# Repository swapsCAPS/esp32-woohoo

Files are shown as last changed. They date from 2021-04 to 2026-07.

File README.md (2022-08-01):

# ESP32 + BME280 IoT Project

## BOM
- DFRobot Firebeetle ESP32-E
- 3.7V LiPo battery
- BME280
- Rectangular rocker switch

## ESP32 WiFi woes
My router does not play nice with ESP32's it seems. Using my phone's hotspot, connecting to the internet and getting a time from NTP works fine.
I **am** getting an IP address, so I know the credentials are correct. But it seems I can't reach the internet, and get disconnected fairly quickly after connecting.  
I fiddled with the security settings and changed from WPA2 + WPA3 to WPA + WPA2 and all of a sudden the ESP32 connected fine. Yay! Wanting to be thorough, I tried using WPA2 + WPA3 mode again to see if I could reproduce my issue. But no! For some weird reason it just keeps connecting now. Needs some more testing. I'll be testing a deep sleep script that sleeps for 10 minutes, then when it wakes up, gets the time and logs if it succeeded or failed to `Serial`.
According to some sources you need to disconnect wifi before deep sleep. I have not been able to reproduce consistent failures by _not_ disconnecting though, so I'll test without that first.
Seems that I successfully got ntp time every 10 minutes. Trying with WPA2 + WPA3 for a couple of cycles. Something weird is going on with my router. I should try turning it off and on again and/or doing a hard reset.  
Could it be there is some weird stateful thing going on?  
**Update:** After tweaking WPA settings back and forth, something in the modem appears to have been nudged. I'm getting consistently connected now, and can not reproduce my issue... I have not touched anything else, I should have probably just reset my modem, before diving into the software side of things.  
**Update 2:** WPA setting does not appear to persist properly, and it appears I have been using WPA + WPA2 this whole time... Come h4ck me!

## Battery life
Experimenting with two devices with their jumper wire cut. Leaving one as is. Will turn them on at the same time. and see how long each will last.  
**Update** I've left two devices side by side, in an attempt to minimize the WiFi interference component of the measurement. Weirdly, after 24 hours the one with its jumper cut is reporting a lower battery level than the one without the jumper cut. It's probably still just too early to say, on top of that, there are a lot of other variables that could influence the reading.

## Weird readings
Sometimes I'm getting way too high or way too low pressure and humidity readings. Experimenting with initializing the BME on start up, instead of right before taking measurement.  
**Update** This has helped, although I still sometimes get a very low pressure reading. It seems like the BME280 needs some time to initialize.

## Devices
Battery powered ESP32 + BME280 modules.  
They take a measurement, send it to an mqtt broker and go to sleep for `TIME_TO_SLEEP`, defined in `./config.h`.  
Arduino code can be found in `./esp32-woohoo.ino`

## Server
Simple rust mqtt scraper to expose prometheus metrics.  
Code can be found in `./mqtt-to-prom`  
Grafana dashboard available in `./mqtt-to-prom/meta/grafana-dashboard.json`

## MQTT
If using mosquitto and running in a safe environment set
```
# /etc/mosquitto/mosquitto.conf
listener 1883 0.0.0.0 # Allow external connections
allow_anonymous true  # We have not set up auth
```

## Build

### esp32-woohoo.ino
- Add the FireBeetle ESP32-E board in Arduino IDE Boards Manager
  - In Arduino IDE -> File -> Preferences -> Additional Boards Manager URLs, add: `http://download.dfrobot.top/FireBeetle/package_DFRobot_index.json`
    - This is for the DFRobot ESP32-E version!
    - Their server is slow af, grab coffee
  - Select the board in Arduino IDE -> Tools -> Board -> DFRobot ESP32 Arduino -> DFRobot FireBeetle ESP32-E
- Ensure the following libs are installed
  - WiFi by Arduino `1.2.7`
  - FastLED by Daniel Garcia `3.5.0`
  - Adafruit Unified Sensor `1.15`
  - Adafruit BME280 Library `2.2.2`
  - https://github.com/marvinroger/async-mqtt-client
- Add a `secret.h` file in the root of the project with WiFi credentials
  ```c
  // ./secret.h
  #define WIFI_SSID "SSID"
  #define WIFI_PASSWORD "hunter1" // lol
  ```

### mqtt-to-prom
Make sure [cross](https://github.com/rust-embedded/cross) is installed
```
cargo install cross
```
If running on raspberry pi 4 with aarch64 run:
```bash
make build-pi
```

## TODO
- [x] Add timer to go back to sleep if connection not made
- [x] Round values to eliminate "noise"
- [x] [bugfix] parsing float goes wrong sometimes, write some tests
  - [x] test this
  - [x] output payload on parse error
  - [ ] check if happens again
- [x] Grafana dashboard
- [x] NTP server call
- [x] Send out time stamps
- [ ] Blink on connection failures?
  - [ ] Needs some experimentation, might substantially reduce batter life
- [ ] Improve battery life
  - [x] Read out SoC (on A0?)
    - [x] Using voltage divider (10KΩ + 20KΩ)
  - [x] Reduce/disable LED on time
  - [x] Reduce amount of measurements taken, i.e. increase sleep time
  - [ ] Go back to deep sleep after several connection failures
  - [ ] Get better idea of battery level percentage (0-4096 but cuts out at 2000 or smth)
  - [ ] If possible light up when battery too low
- [x] Add last will on connect()
    - [ ] Decided to skip this for now. Will do server side most likely.
- [ ] Auto config server. Loop over serial ports, check for devices and flash config to them.
  - [ ] Auto config server
  - [ ] Use EEPROM to store wifi credentials, broker location, etc.

## Media
3D printed case, check `./stl` for files.
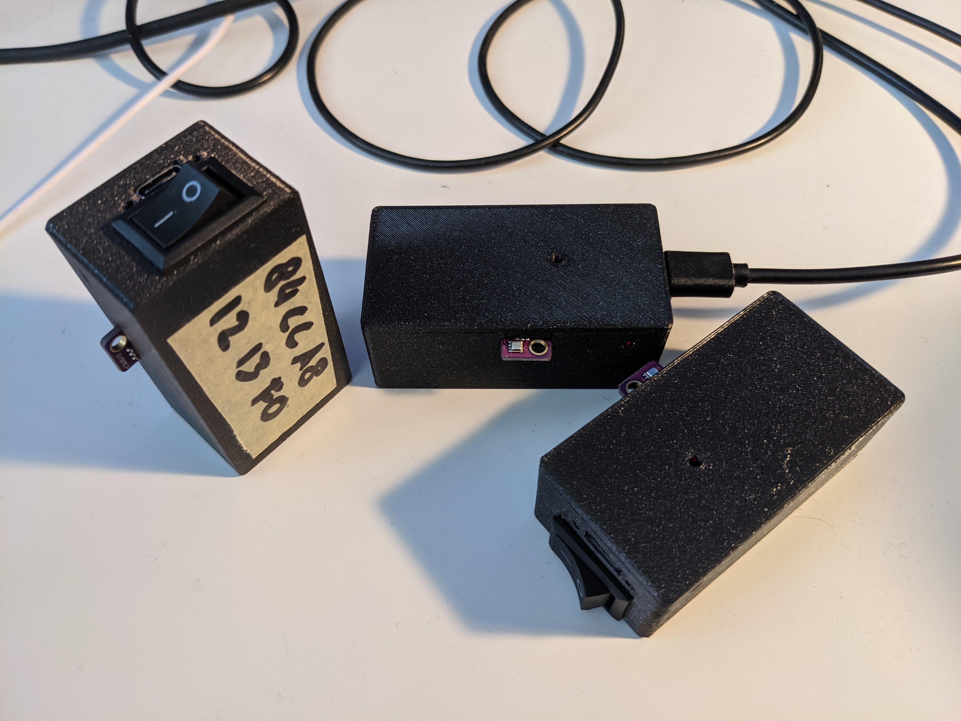
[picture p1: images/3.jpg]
Aint they cute?!


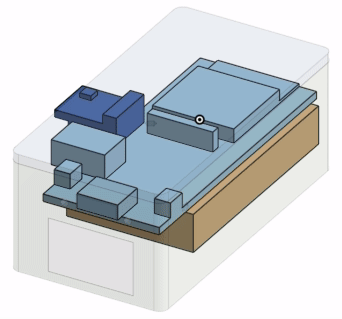
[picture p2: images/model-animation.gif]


Deep sleep, wake, connect wifi, connect mqtt, take measurement, send measurement, deep sleep...  
Oooh look at the pretty lights!

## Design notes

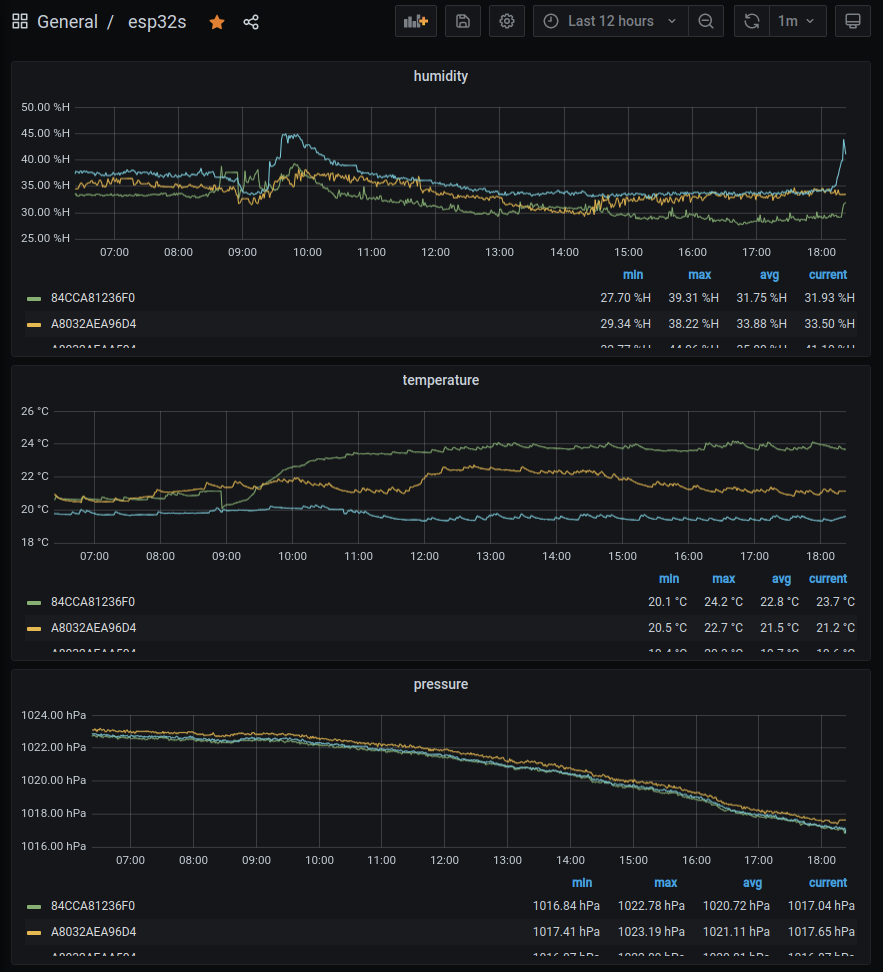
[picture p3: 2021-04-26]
images/grafana-dashboard.png

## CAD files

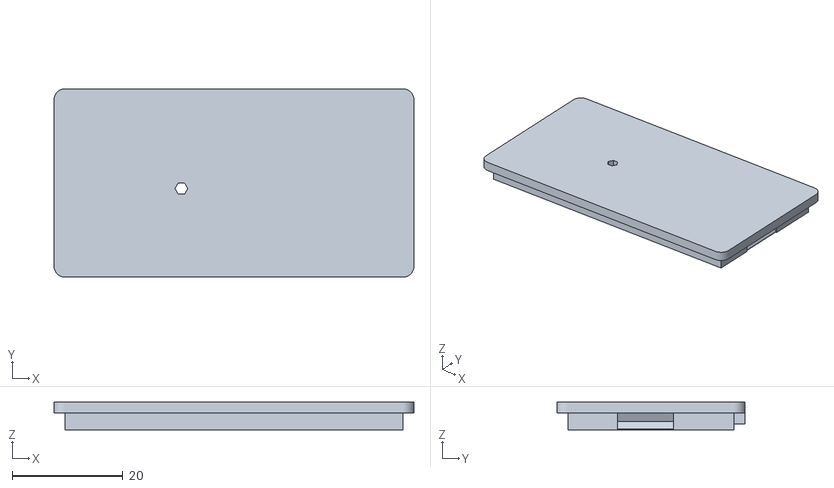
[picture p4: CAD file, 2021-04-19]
stl/hum-sensor-v2 - lid.stl
65.0 x 34.0 x 5.00

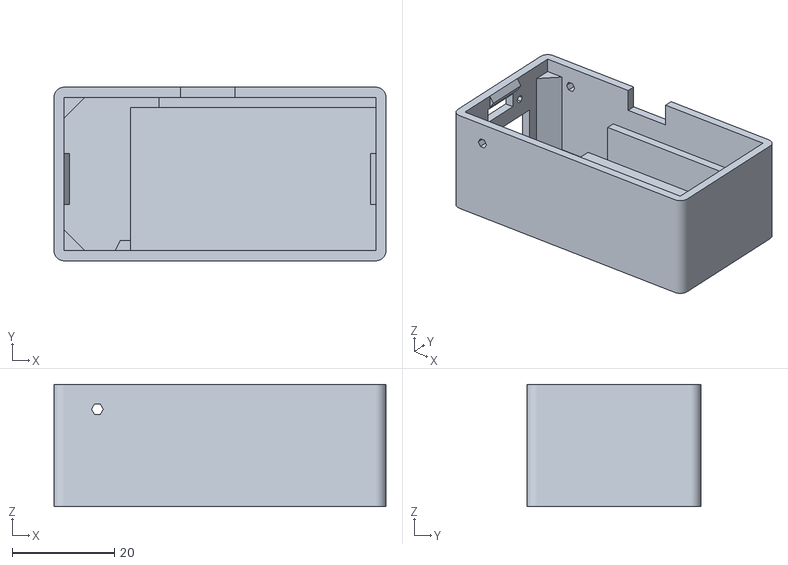
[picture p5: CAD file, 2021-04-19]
stl/hum-sensor-v2 - box.stl
65.0 x 34.0 x 23.9

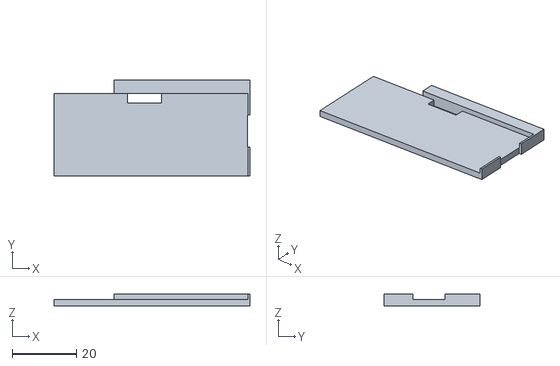
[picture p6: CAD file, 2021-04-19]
stl/hum-sensor-v2 - shim.stl
60.8 x 29.9 x 3.60

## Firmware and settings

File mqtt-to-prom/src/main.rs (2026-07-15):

#[macro_use]
extern crate prometheus;
#[macro_use]
extern crate lazy_static;
#[macro_use]
extern crate log;
extern crate pretty_env_logger;

use prometheus::{Encoder, GaugeVec, TextEncoder};
use rumqttc::{Client, Event, Incoming, MqttOptions, QoS};
use std::env;
use std::io::prelude::*;
use std::net::{TcpListener, TcpStream};
use std::str;
use std::thread;

lazy_static! {
    static ref TEMPERATURE_GAUGE: GaugeVec =
        register_gauge_vec!("esp32_temperature", "Temperature", &["mac"]).unwrap();
    static ref HUMIDITY_GAUGE: GaugeVec =
        register_gauge_vec!("esp32_humidity", "Humidity", &["mac"]).unwrap();
    static ref PRESSURE_GAUGE: GaugeVec =
        register_gauge_vec!("esp32_pressure", "Pressure", &["mac"]).unwrap();
    static ref BATTERY_LEVEL: GaugeVec =
        register_gauge_vec!("esp32_bat_lvl", "Battery level", &["mac"]).unwrap();
    static ref EPOCH: GaugeVec = register_gauge_vec!("esp32_epoch", "Epoch", &["mac"]).unwrap();
    static ref MEASUREMENT_SUCCESS: GaugeVec = register_gauge_vec!(
        "esp32_measurement_success",
        "Times taking a measurement succeeded",
        &["mac"]
    )
    .unwrap();
    static ref MEASUREMENT_FAILURE: GaugeVec = register_gauge_vec!(
        "esp32_measurement_failure",
        "Times measurement failed",
        &["mac"]
    )
    .unwrap();
}

fn main() {
    pretty_env_logger::init();
    info!("Starting mqtt thread...");

    let mqtt_host = env::var("MQTT_HOST").unwrap_or(String::from("localhost"));
    let bind_address = env::var("TCP_BIND_ADDR").unwrap_or(String::from("localhost:19090"));

    info!("mqtt_host {}", mqtt_host);
    info!("bind_address {}", bind_address);

    // --- MQTT Thread ---
    thread::spawn(move || {
        let mut mqttoptions = MqttOptions::new("esp32-server", mqtt_host, 1883);
        mqttoptions.set_keep_alive(5);

        let (mut client, mut connection) = Client::new(mqttoptions, 10);

        // Wrap subscription in case of early errors
        if let Err(e) = client.subscribe("sensors/thp/+", QoS::AtMostOnce) {
            error!("Failed to subscribe: {:?}", e);
        }

        // Process MQTT notifications
        for (i, notification) in connection.iter().enumerate() {
            // Every 1000 events, log a heartbeat to see if this loop is flooding
            if i % 1000 == 0 {
                debug!("MQTT Loop Heartbeat: processed {} events", i);
            }

            match notification {
                Ok(Event::Incoming(Incoming::Publish(p))) => {
                    let mac = match p.topic.split("/").last() {
                        Some(m) => m,
                        None => {
                            warn!("Failed to extract mac from topic: {}", p.topic);
                            continue;
                        }
                    };

                    let payload = match str::from_utf8(&p.payload) {
                        Ok(v) => v,
                        Err(_) => {
                            warn!("Invalid UTF-8 payload");
                            continue;
                        }
                    };

                    let split: Vec<&str> = payload.split(",").collect();

                    if let [temp, h, p, b, epoch, success, failure] = &split[..] {
                        if let Ok(result) = temp.trim().parse::<f64>() {
                            TEMPERATURE_GAUGE
                                .with_label_values(&[mac])
                                .set((result * 4.0).round() / 4.0);
                        }
                        if let Ok(result) = h.trim().parse::<f64>() {
                            HUMIDITY_GAUGE
                                .with_label_values(&[mac])
                                .set((result * 4.0).round() / 4.0);
                        }
                        if let Ok(result) = p.trim().parse::<f64>() {
                            PRESSURE_GAUGE
                                .with_label_values(&[mac])
                                .set((result * 4.0).round() / 4.0);
                        }
                        if let Ok(result) = b.trim().parse::<f64>() {
                            BATTERY_LEVEL.with_label_values(&[mac]).set(result);
                        }
                        if let Ok(result) = epoch.trim().parse::<f64>() {
                            EPOCH.with_label_values(&[mac]).set(result);
                        }
                        if let Ok(result) = success.trim().parse::<f64>() {
                            MEASUREMENT_SUCCESS.with_label_values(&[mac]).set(result);
                        }
                        if let Ok(result) = failure.trim().parse::<f64>() {
                            MEASUREMENT_FAILURE.with_label_values(&[mac]).set(result);
                        }
                    } else {
                        warn!("Could not split payload from {}", payload);
                    }
                }
                Ok(_other) => {
                    // Ignore non-publish events (pings, acks, etc) to prevent log flooding
                }
                Err(e) => {
                    error!("MQTT connection error: {:?}", e);
                    // Crucial: Sleep on error to prevent spinning during broker outage
                    thread::sleep(std::time::Duration::from_secs(2));
                }
            }
        }
    });

    // --- TCP Server (Prometheus Scrape Endpoint) ---
    let listener = TcpListener::bind(bind_address).unwrap();
    info!("Starting server...");

    for stream in listener.incoming() {
        let mut stream = match stream {
            Ok(s) => s,
            Err(e) => {
                error!("TCP incoming stream connection error: {:?}", e);
                thread::sleep(std::time::Duration::from_millis(50)); // Prevent hot loop if OS runs out of FDs
                continue;
            }
        };

        debug!("Request received");
        let mut req = [0; 1024];

        // Read from stream defensively
        match stream.read(&mut req) {
            Ok(0) => {
                // Client connected and immediately closed (EOF)
                debug!("Client closed connection immediately (0 bytes read)");
                continue;
            }
            Ok(n) => {
                debug!("Read {} bytes", n);
            }
            Err(e) => {
                warn!("Failed to read from TCP stream: {:?}", e);
                continue;
            }
        }

        let mut buffer = vec![];
        let encoder = TextEncoder::new();
        let metric_families = prometheus::gather();
        encoder.encode(&metric_families, &mut buffer).unwrap();

        let res = format!(
            "HTTP/1.1 200 OK\r\nContent-Length: {}\r\nConnection: close\r\n\r\n{}",
            buffer.len(),
            str::from_utf8(&buffer).unwrap()
        );

        if let Err(e) = stream.write_all(res.as_bytes()) {
            warn!("Failed to write TCP response: {:?}", e);
        }
        let _ = stream.flush();
    }
}

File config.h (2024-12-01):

#define SEALEVELPRESSURE_HPA 1013.00

// Time to sleep after taking a measurement
#define TIME_TO_SLEEP 10 * 60

// Go back to sleep if no measurement was taken withing this time
#define DEADMAN_SWITCH_MS 30 * 1000

#define MQTT_HOST IPAddress(192, 168, 178, 147)
#define MQTT_PORT 1883

// Hooked up using voltage divider
// In this case using 10K and 22K resistors I had laying around
int batteryLevelPin = A0;

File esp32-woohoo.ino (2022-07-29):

#include <FastLED.h>
#include <WiFi.h>
#include <Wire.h>
#include <Adafruit_Sensor.h>
#include <Adafruit_BME280.h>
#include <AsyncMqttClient.h>
#include "time.h"

#include "secret.h"
#include "config.h"

extern "C" {
#include "freertos/FreeRTOS.h"
#include "freertos/timers.h"
}

#define NUM_LEDS 1
#define DATA_PIN 5
#define CLOCK_PIN 13
#define uS_TO_S_FACTOR 1000000
#define I2C_SDA 21
#define I2C_SCL 22

RTC_DATA_ATTR int successCounter = 0;
RTC_DATA_ATTR int failureCounter = 0;

bool succeeded = false;

const char* ntpServer = "pool.ntp.org";
unsigned long epochTime;

TimerHandle_t deadmanSwitch;

CRGB leds[NUM_LEDS];
Adafruit_BME280 bme;

// Recommended delay time between reading from Bosch Sensortec
unsigned long delayTime;

byte macAddress[6];

char ssid[32];
char pass[20];

char macAddressStrArr[18];
char topicBuffie[32];
char pubBuffie[128];
char valBuffie[64];

AsyncMqttClient mqttClient;

void _configTime() {
    Serial.println("-- _configTime()");
    configTime(0, 0, ntpServer);
}

// Function that gets current epoch time
unsigned long getTime() {
  Serial.println("-- getTime()");
  time_t now;
  struct tm timeinfo;
  Serial.println("-- getTime() getting local time");
  if (!getLocalTime(&timeinfo)) {
    Serial.println("-- getTime() could not get time : (");
    return(0);
  }
  time(&now);
  Serial.println("-- getTime() done");

  return now;
}

void array_to_string(byte array[], unsigned int len, char buffer[]) {
  for (unsigned int i = 0; i < len; i++) {
    byte nib1 = (array[i] >> 4) & 0x0F;
    byte nib2 = (array[i] >> 0) & 0x0F;

    uint8_t offset = i;

    buffer[i*2+0] = nib1  < 0xA ? '0' + nib1  : 'A' + nib1  - 0xA;
    buffer[i*2+1] = nib2  < 0xA ? '0' + nib2  : 'A' + nib2  - 0xA;

    if (i == len - 1) { break; }

    buffer[i*2+2] = ':';
  }
  buffer[len*2] = '\0';
}

void setLED(uint32_t val) {
  leds[0] = val;
  FastLED.show();
}

void setMacAddressStr() {
  array_to_string(macAddress, 6, macAddressStrArr);
}

void setTopicBuffie() {
  strcat(topicBuffie, "sensors/thp/");
  strcat(topicBuffie, macAddressStrArr);
}

void blinkDelay(uint16_t ival, uint8_t times, uint32_t color) {
  for (uint8_t i = 0; i < times; i++) {
    setLED(color);
    delay(ival / 2);
    setLED(0x000000);
    delay(ival / 2);
  }
}

void onDeadmanSwitch() {
  Serial.println("-- onDeadmanSwitch() triggered!");
  goToSleep();
}

void connectToWifi() {
  Serial.println("-- connectToWifi");
  WiFi.begin(WIFI_SSID, WIFI_PASSWORD);
}

void connectToMqtt() {
  Serial.println("-- connectToMqtt");
  mqttClient.connect();
}

void onWiFiEvent(WiFiEvent_t event) {
  Serial.printf("-- onWiFiEvent() event: %d\n", event);
  switch(event) {
    case SYSTEM_EVENT_STA_GOT_IP:
      Serial.print("-- onWiFiEvent() connected to ");
      Serial.print(ssid);
      Serial.print(" with ");
      Serial.print(pass);
      Serial.print(", own ip: [");
      Serial.print(WiFi.localIP());
      Serial.println("]");

      _configTime();
      WiFi.macAddress(macAddress);
      setMacAddressStr();
      setTopicBuffie();

      connectToMqtt();

      break;
    case SYSTEM_EVENT_STA_DISCONNECTED:
      Serial.println("-- onWiFiEvent() disconnected");

      break;
  }
}

void initWiFi() {
  Serial.println("-- initWiFi() start");

  Serial.print("-- initWiFi() configured for: \"");
  Serial.print(ssid);
  Serial.print("\" with \"");
  Serial.print(pass);
  Serial.println("\"");

  WiFi.mode(WIFI_STA);
  WiFi.onEvent(onWiFiEvent);

  Serial.println("-- initWiFi() finish");
}

void onMqttDisconnect(AsyncMqttClientDisconnectReason reason) {
  Serial.printf("-- onMqttDisconnect() disconnecting WiFi %d\n", reason);

  WiFi.disconnect();
}


void onMqttConnect(bool sessionPresent) {
  Serial.println("-- onMqttConnect() connected");

  measure();

  mqttClient.disconnect();

  goToSleep();
}

void goToSleep() {
  Serial.println("-- goToSleep()");

  if (succeeded == true) {
    successCounter += 1;
  } else {
    failureCounter += 1;
  }

  esp_deep_sleep_start();
}

void initMQTT() {
  Serial.println("-- initMQTT() start");

  mqttClient.setServer(MQTT_HOST, MQTT_PORT);
  mqttClient.setClientId(macAddressStrArr);
  mqttClient.onDisconnect(onMqttDisconnect);
  mqttClient.onConnect(onMqttConnect);

  Serial.println("-- initMQTT() finish");
}

void print_wakeup_reason(){
  esp_sleep_wakeup_cause_t wakeup_reason;

  wakeup_reason = esp_sleep_get_wakeup_cause();

  switch(wakeup_reason) {
    case ESP_SLEEP_WAKEUP_EXT0:     Serial.println("-- Wakeup caused by external signal using RTC_IO"); break;
    case ESP_SLEEP_WAKEUP_EXT1:     Serial.println("-- Wakeup caused by external signal using RTC_CNTL"); break;
    case ESP_SLEEP_WAKEUP_TIMER:    Serial.println("-- Wakeup caused by timer"); break;
    case ESP_SLEEP_WAKEUP_TOUCHPAD: Serial.println("-- Wakeup caused by touchpad"); break;
    case ESP_SLEEP_WAKEUP_ULP:      Serial.println("-- Wakeup caused by ULP program"); break;
    default:                        Serial.printf("-- Wakeup was not caused by deep sleep: %d\n", wakeup_reason); break;
  }
}

void measure() {
  Serial.println("-- measure() start");

  /* setLED(0xFF00FF); */

  bme.takeForcedMeasurement();

  // Trying really hard to avoid String(), cause that's what the internet tells me to do...
  dtostrf(bme.readTemperature(), 6, 2, valBuffie);
  strcat(pubBuffie, valBuffie);
  strcat(pubBuffie, ",");

  dtostrf(bme.readHumidity(), 5, 2, valBuffie);
  strcat(pubBuffie, valBuffie);
  strcat(pubBuffie, ",");

  dtostrf(bme.readPressure() / 100.0f, 7, 2, valBuffie);
  strcat(pubBuffie, valBuffie);
  strcat(pubBuffie, ",");

  itoa(analogRead(batteryLevelPin), valBuffie, 10);
  strcat(pubBuffie, valBuffie);
  strcat(pubBuffie, ",");

  itoa(getTime(), valBuffie, 10);
  strcat(pubBuffie, valBuffie);
  strcat(pubBuffie, ",");

  itoa(successCounter, valBuffie, 10);
  strcat(pubBuffie, valBuffie);
  strcat(pubBuffie, ",");

  itoa(failureCounter, valBuffie, 10);
  strcat(pubBuffie, valBuffie);

  Serial.print("-- measure() publishing: ");
  Serial.println(pubBuffie);

  mqttClient.publish(topicBuffie, 1, false, pubBuffie);

  succeeded = true;

  Serial.println("-- measure() finish");
}
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

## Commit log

2021-04-11 connect to wifi and set rgb led accoringly
2021-04-19 deep sleep + fix wifi conn retry + wip bme measurement
    Not sure why this `WiFi.disconnect()` is helping though...
    [esp32-woohoo.ino]
2021-04-19 fix bme init and take measurement
    [esp32-woohoo.ino]
2021-06-09 Stop using LED for longer operation + read A0 for battery level
2021-06-09 read out battery level
2021-06-09 show bat_lvl in grafana + new ARM build
2021-06-11 log payload on parse error
    [main.rs]
2021-06-11 round values to eliminate noise a bit
    [main.rs]
2021-06-11 missed it pressure rounding!
    [main.rs]
2021-09-12 tweak arduino log
2022-05-28 add deadman switch to go back to sleep if no measurement was taken
2022-07-25 Sync with NTP + count success/failures
    [esp32-woohoo.ino]
2022-07-25 mqtt-to-prom epoch, success and failure gauges
    [main.rs]
